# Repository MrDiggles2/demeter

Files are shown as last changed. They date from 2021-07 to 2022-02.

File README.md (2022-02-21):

# Demeter

Low power, wireless plant moisture sensors.

|Module|Description|
|--|--|
|`sensor`|Sensor built on ESP12E. Publishes data to MQTT. Low power usage, can last months on a single battery charge|
|`aggregator`|Node server that collected sensor data and exposes it via API|
|`display`|ESP12E and eInk module. Pulls data from server and displays data at a slow cadence|

<table>
  <tr>
    <td></td>
    <td></td>
  </tr>
</table>

### TODOs

* Figure out how to interpret raw values from sensors for display
* Hook up pager duty

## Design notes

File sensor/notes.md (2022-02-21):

### Chip

Using ESP8266 Node MCU CP2102

Uses ESP12E module

https://www.aliexpress.com/item/1005001636474859.html?spm=a2g0s.9042311.0.0.6a644c4dI5g24P

### Power

* Battery
  * https://www.aliexpress.com/item/5Pcs-3-7V-1200mAh-Lipo-Battery-Charger-for-Syma-X5SW-X5SC-M18-H5P-RC-Drone/1005001450744187.html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
    * Have to trim connector to fit on chip
  * Capacity: 1200 mAh
  * Volage: 4.2 max, dead at 3.4: https://learn.adafruit.com/li-ion-and-lipoly-batteries/voltages

* Load

  * Deep sleep
    * Supposed to use 20 uA: https://randomnerdtutorials.com/esp8266-deep-sleep-with-arduino-ide/
    * Currently, uses ~14mA.
    * Due to "dev" components on chip
      * Other people having issues: https://github.com/esp8266/Arduino/issues/4957#issuecomment-516771848
      * Cutting power to the bits: https://tinker.yeoman.com.au/2016/05/29/running-nodemcu-on-a-battery-esp8266-low-power-consumption-revisited/
        * **Botched a chip trying this, ordered a magnifying glass to see if that helps**
          * Marked with an X
          * Eating 35 mA constantly for some reason
    * Probably have to just to the underlying ESP12E chip
      * Need 3.3V regulator (have HT7333)
      * ~~Need to figure out how to program~~ - Made jigs by taking apart ESP8266 
      * **It's lasted several months without issue**
  * Active
    * Measured average of 70-80 mA while active
    * ~5 seconds to wake up, measure, and publish
    * 350 mAs per check

### Sensor

* Consistent reads with same sensor
  * Fluctuates even when reading within 5 minutes of each other
  * Potentially due to high impedance on sensor, started experiment with 100k and 220k resistors
    * Named as "pcb-test-w-220uF-new-resistors"

* ~~Normalizing reads between sensors~~ - **No longer necessary, fixed accuracy by increasing resistance on voltage dividers**
  * Usually within 20% of each other
  * Have to normalize somehow and map to 1-100 range
    * Manual?
    * Regression?
      * Both linear and logrithimic gets really weird.
      * Needs more experimentig

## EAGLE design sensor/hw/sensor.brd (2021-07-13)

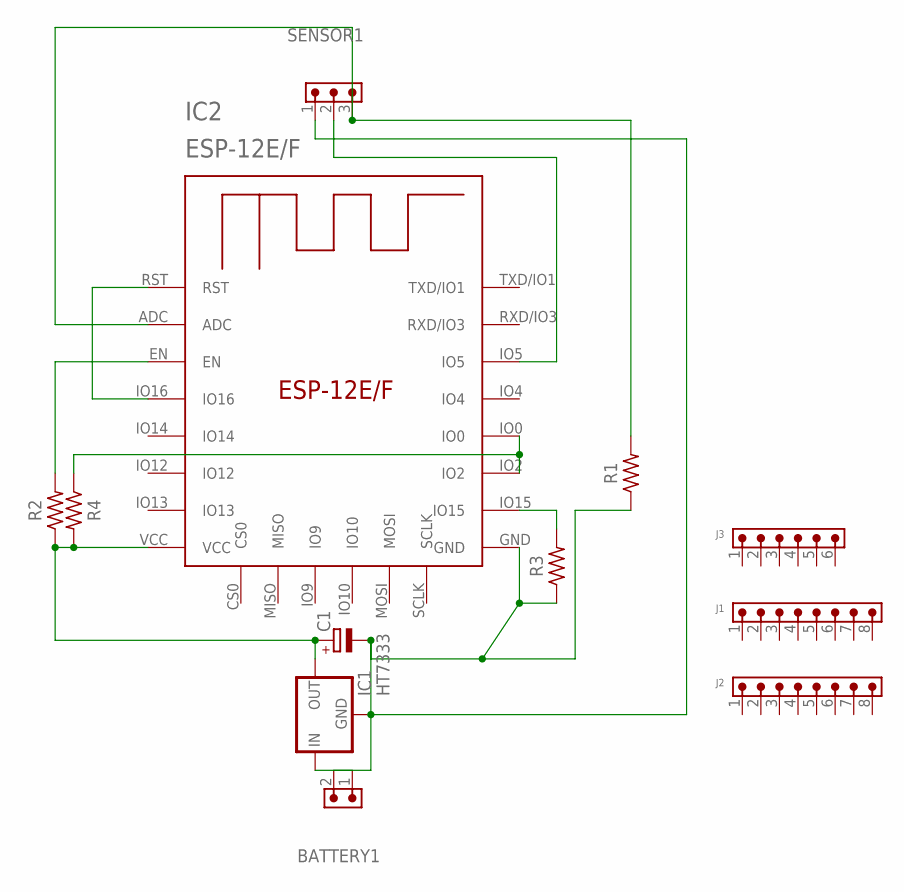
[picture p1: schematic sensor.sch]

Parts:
BATTERY1: 6130XX11121_61300211121; 61300211121
C1: CPOL-EUE2-5; E2-5
IC1: HT7333; SOT-89
IC2: ESP-12E/F; ESP-12E
J1, J2: 6200XX11121_62000811121; 62000811121
J3: 6200XX11121_62000611121; 62000611121
R1, R2, R3, R4: R-US_AXIAL-7.2MM-PITCH; RESAD724W46L381D178B
SENSOR1: 6130XX11121_61300311121; 61300311121

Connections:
unnamed: IC2.IO5, SENSOR1.2
unnamed: IC2.IO0, IC2.IO2, R4.1
unnamed: IC2.ADC, R1.2, SENSOR1.3
unnamed: BATTERY1.1, IC1.3 (IN), IC1.4 (IN)
unnamed: IC2.EN, R2.2
unnamed: IC2.IO16, IC2.RST
unnamed: IC2.IO15, R3.2
unnamed: BATTERY1.2, C1.-, IC1.2 (GND), IC2.GND, R1.1, R3.1, SENSOR1.1
unnamed: C1.+, IC1.1 (OUT), IC2.VCC, R2.1, R4.2

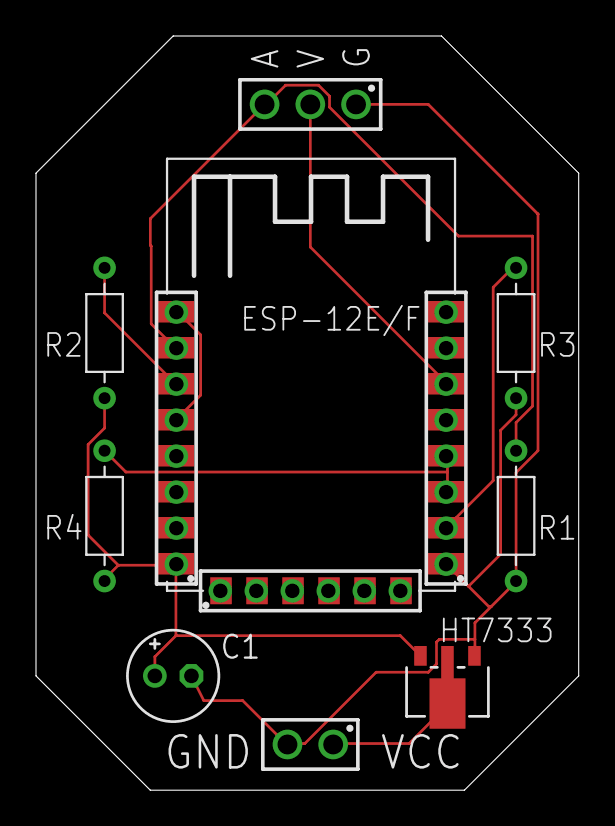
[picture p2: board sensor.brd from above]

Board: 2 copper layers, 30.1 x 41.9 mm, 12 parts (0 on the bottom side), 9 nets.

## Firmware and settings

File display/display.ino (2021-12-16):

#include <Arduino.h>

#include <ESP8266WiFi.h>
#include <ESP8266HTTPClient.h>
#include <ArduinoJson.h>

#include "DEV_Config.h"
#include "EPD.h"
#include "GUI_Paint.h"
#include <stdlib.h>

// Statically declare to keep canvas allocated on the stack to save on heap space
// H * W / byte
UBYTE *canvas = new UBYTE[400 * 300 / 8];
int LIMIT = 10;
int DATA_ARRAY_SPACE = 1024;

/**
 * Fills *dataArray with response from API. Return true on success, false otherwise.
 */
bool fetchDataArray(DynamicJsonDocument *dataArray) {
  String ssid     = "Bebes on Parade";
  String password = "lameepmeep";
  WiFiClient wifiClient;
  
  String apiUrl = "http://raspberrypi.local:3000/status?compact=true&count=" + String(LIMIT);
  HTTPClient httpClient;

  Serial.println("Connecting to " + String(ssid));
  WiFi.mode(WIFI_STA);
  WiFi.begin(ssid, password);
  while (WiFi.status() != WL_CONNECTED) {
    delay(500);
    Serial.print(".");
  }
  Serial.println("Connected");

  String rawJson;

  Serial.println("Begin GET");

  if (httpClient.begin(wifiClient, apiUrl)) {

    httpClient.setTimeout(30000); // 30 seconds
    int httpCode = httpClient.GET();
    
    // httpCode will be negative on error
    if (httpCode > 0) {
      // HTTP header has been send and Server response header has been handled
      Serial.printf("[HTTP] GET response code: %d\n", httpCode);

      if (httpCode == HTTP_CODE_OK) {
        rawJson = httpClient.getString();
        Serial.println("Raw JSON: " + rawJson);
      }
    } else {
      Serial.printf("HTTP GET failed, error: %s\n", httpClient.errorToString(httpCode).c_str());
      return false;
    }
    
    httpClient.end();
  } else {
    Serial.println("Unable to connect via HTTP");
    return false;
  }

  // Parse JSON object
  DeserializationError error = deserializeJson(*dataArray, rawJson);
  if (error) {
    Serial.print(F("deserializeJson() failed: "));
    Serial.println(error.f_str());
    return false;
  }

  return true;
}

/**
 * Initializes display for drawing
 */
void initializeDisplay() {
  DEV_Module_Init();
  EPD_4IN2_Init();
  EPD_4IN2_Clear();
  DEV_Delay_ms(500);
  Paint_NewImage(canvas, EPD_4IN2_WIDTH, EPD_4IN2_HEIGHT, 0, WHITE);
  Paint_SetRotate(ROTATE_90);
  Paint_Clear(WHITE);
}

/**
 * Draws the status of a single sensor
 */
void drawSensorStatus(int index, String name, int value, int isAlive) {
  Serial.println("Drawing [" + String(index) + "] " + name + ": " + String(value) + ", " + String(isAlive));

  if (isAlive == 0) name = "!" + name;
  int bufferSize = name.length() + 1;
  char nameAsChar[bufferSize];
  name.toCharArray(nameAsChar, bufferSize);

  // Max width = 300
  // Max height = 400

  UWORD startX = 1;
  UWORD startY = 10 + (index * 30);
  UWORD barStartX = 150;
  UWORD barEndX = barStartX + 145;
  UWORD barEndY = startY + 20;

  // Draw the name of the sensor
  Paint_DrawString_EN(
    startX,
    startY + 1,
    nameAsChar,
    &Font20,
    WHITE,
    BLACK
  );

  // Draw the outline of the bar
  Paint_DrawRectangle(
    barStartX, startY,
    barEndX, barEndY,
    BLACK,
    DOT_PIXEL_2X2,
    DRAW_FILL_EMPTY
  );

  UWORD borderWidth = 4;
  UWORD fillBarX = map(value, 0, 100, barStartX + borderWidth, barEndX - borderWidth);

  // Draw the fill of the bar
  Paint_DrawRectangle(
    barStartX + borderWidth, startY + borderWidth,
    fillBarX, barEndY - borderWidth + 1,
    BLACK,
    DOT_PIXEL_1X1,
    DRAW_FILL_FULL
  );
}

void setup() {
  Serial.begin(9600); // open serial port, set the baud rate to 9600 bps

  DynamicJsonDocument dataArray(DATA_ARRAY_SPACE);
  bool success = fetchDataArray(&dataArray);
  if (!success) {
    Serial.println("Failed to fetch data array");
    return;
  }

  int dataSize = dataArray.size();
  Serial.println("Number of sensors: " + String(dataSize));

  initializeDisplay();

  for (int i = 0; i < dataSize; i++) {
    JsonObject obj = dataArray[i].as<JsonObject>();

    drawSensorStatus(
      i,
      obj["n"],     // sensor.name
      obj["v"],     // moistureLevel
      obj["a"]      // isAlive as 0,1
    );
  }

  Serial.println("Displaying canvas on screen");
  EPD_4IN2_Display(canvas);

  dataArray.clear();
  Serial.println("Done");
}

void loop() {
  // Left intentionally blank
}

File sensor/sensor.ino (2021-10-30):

#include <ESP8266WiFi.h>
#include <PubSubClient.h>
#include <Arduino.h>

extern "C" {
  #include <user_interface.h>
}

const String sensorName = "ignore";

const byte SENSOR_OUT = A0;
const byte SENSOR_VCC = D1;

const char* ssid     = "Bebes on Parade";
const char* password = "lameepmeep";
WiFiClient espClient;

const char* mqttHost = "raspberrypi.local";
PubSubClient client(espClient);

// Publishes moisture value
void publish(int moistureValue) {
  Serial.println("Connecting to " + String(ssid));

  delay(100);
  WiFi.mode(WIFI_STA);

  WiFi.begin(ssid, password);
  
  while (WiFi.status() != WL_CONNECTED) {
    delay(500);
    Serial.print(".");
  }
 
  Serial.println("");
  Serial.println("WiFi connected");  
  Serial.println("IP address: ");
  Serial.println(WiFi.localIP());
  Serial.print("Netmask: ");
  Serial.println(WiFi.subnetMask());
  Serial.print("Gateway: ");
  Serial.println(WiFi.gatewayIP());

  client.setServer(mqttHost, 1883);

  int attempts = 0;
  int maxAttempts = 3;

  // Loop until we're reconnected
  while (!client.connected()) {
    if (attempts++ >= maxAttempts) {
      Serial.println("Reached max MQTT connection attempts");
      Serial.println("Failed to publish");
      return;
    }

    Serial.print("Attempting MQTT connection (" + String(attempts) + "/" + String(maxAttempts) + "): ");

    String clientId = "sensor_" + sensorName;

    if (client.connect(clientId.c_str())) {
      Serial.println("connected to mqtt");
    } else {
      Serial.println("failed, rc=" + String(client.state()) + " trying again in 5 seconds");
      delay(5000);
    }
  }

  client.loop();

  client.publish(("$SYS/demeter/readings/" + sensorName + "/raw").c_str(), String(moistureValue).c_str());
  Serial.println("Published successfully");

  client.disconnect();
}


// Reads moisture value from sensor
int readMoisture() {
  // Power up the sensor
  digitalWrite(SENSOR_VCC, 1);

  // Wait a little for it get fully powered
  delay(500);

  int moistureValue = analogRead(SENSOR_OUT);
  Serial.println("Recorded value: " + String(moistureValue));

  // Power down the sensor
  digitalWrite(SENSOR_VCC, 0);

  return moistureValue;
}

// Enter max deep sleep cycle the provided number of times. This is usually around 3.5 hours
void deepSleepCycles(uint32_t numCycles) {
  // Read counter from memory
  uint32_t resetCounter = 0;
  ESP.rtcUserMemoryRead(0, &resetCounter, sizeof(resetCounter));
  // Increment counter
  resetCounter++;
  
  Serial.println("Deep sleep progress: " + String(resetCounter) + "/" + String(numCycles));

  ESP.rtcUserMemoryWrite(0, &resetCounter, sizeof(resetCounter));

  if (resetCounter <= numCycles) {
    ESP.deepSleep(1e6 * 60 * 60);
  } else {
    Serial.println("Deep sleep complete!");
  }

  resetSleepCounter();
}

void resetSleepCounter() {
  uint32_t resetCounter = 0;
  ESP.rtcUserMemoryWrite(0, &resetCounter, sizeof(resetCounter));
}

/////////////////////
// Start main loop //
/////////////////////

void setup() {
  Serial.begin(9600);

  pinMode(SENSOR_VCC, OUTPUT);
  digitalWrite(SENSOR_VCC, 0);

  // Reset counter if hard reset is detected

  Serial.println("Reset reason: " + ESP.getResetReason());

  if (ESP.getResetReason() != "Deep-Sleep Wake") {
    Serial.println("Hard reset: zeroing reset counter.");
    resetSleepCounter();
  } else {
    deepSleepCycles(6);
  }

  int moistureValue = readMoisture();
  publish(moistureValue);

  deepSleepCycles(6);
}

void loop() {
  // deep sleep restarts esp, setup() acts as loop
}

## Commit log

2020-11-07 adds code to preserve max and min values between resets
    [demeter.ino]
2020-11-07 moves publishing to separate function. adds hard reset option for bounds
    [demeter.ino]
2021-02-24 rearranges some files; fixes dependencies
    [sensor.ino]
2021-02-24 final touch for sensor
2021-03-04 fixes deepsleep; adds timestamp column
    [sensor.ino]
2021-03-05 integrates with current data
2021-03-25 sensor updates
2021-03-25 adds support for name filtering
2021-06-08 updates to power sensor with gpio instead of vcc
2021-07-13 adds EAGLE files
    [sensor.brd, sensor.sch]
2021-10-30 puts in a sample value since i'm too lazy to figure out the caluclation right now
2021-11-02 adds sensor notes; adds initial display code

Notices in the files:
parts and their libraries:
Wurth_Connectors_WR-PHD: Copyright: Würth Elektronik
